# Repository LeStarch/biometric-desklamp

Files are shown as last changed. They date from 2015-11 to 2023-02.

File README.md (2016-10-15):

# Fingerprint Controlled Biometric Desk Lamp
All the files required to build the finger-print enabled LED super lamp.

Files include Arduino code, KiCad files, etc.

## Functional Diagram

Lamp Functional Design Lamp functional design

## 5V1A Power Supply
Used to power the Arduino and the cooling fan, this power supply is slightly under powered due to the narrow trace width between the components. Thus it is capible of supplying ~600mA. This is appears to be sufficient for the Teensy 3.2, finger-print scanner, and LED cooling fan.

**Needed improvments:** Trace widths need to be increased to reliably supply the advertised 1A power. 100k resistor should be replaced with surface mount equivalent.

## LED Driver
LEDs must be driven at a constant current (not voltage) in order to maximize their life expectancy. This driver produces a 1A constant ~30V supply for a high-powered LED module.  It is based on the Texas Instruments LM-3409 chip.  See: https://github.com/LeStarch/lm3409-calc for how the components were calculated.

**Needed Improvments:** 

Awaiting assembly.

**Issues Corrected in v2:** Trace widths may be too small to reliably cary 1A for LED driving. In practice, the lamp is stable, but trace widths should be increased in "an abundance of caution".

P-type MOSFET has a reversed layout and thus should be corrected in version 2.

## Nano Code (and now Teensy as well)
Code written using the Arduino libraries, which interfaces with the fingerprint reader and controls PWM signals used to drive the cooling fan and LED driver enable line.

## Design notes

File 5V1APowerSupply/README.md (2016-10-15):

5V Driver
=========

This is now unused, as it was merged into a singleton board.

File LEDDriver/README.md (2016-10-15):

Kicad Files
===========

This directory contains the necessary schematic files, net, and pcb files for the Kicad design of the biometric desklamp.

Note: the 5v driver has been added as a sub-schematic

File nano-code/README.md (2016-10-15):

Arduino Software
================

This is the software written for arduino to interface with the biometric desklamp.  This software is written in C++ and uses the arduino libraries in order to to handle IO and UART.

''Note:'' this software was developed with the help of Platform-IO and thus it is recommended that the user use Platform-IO to build/upload.

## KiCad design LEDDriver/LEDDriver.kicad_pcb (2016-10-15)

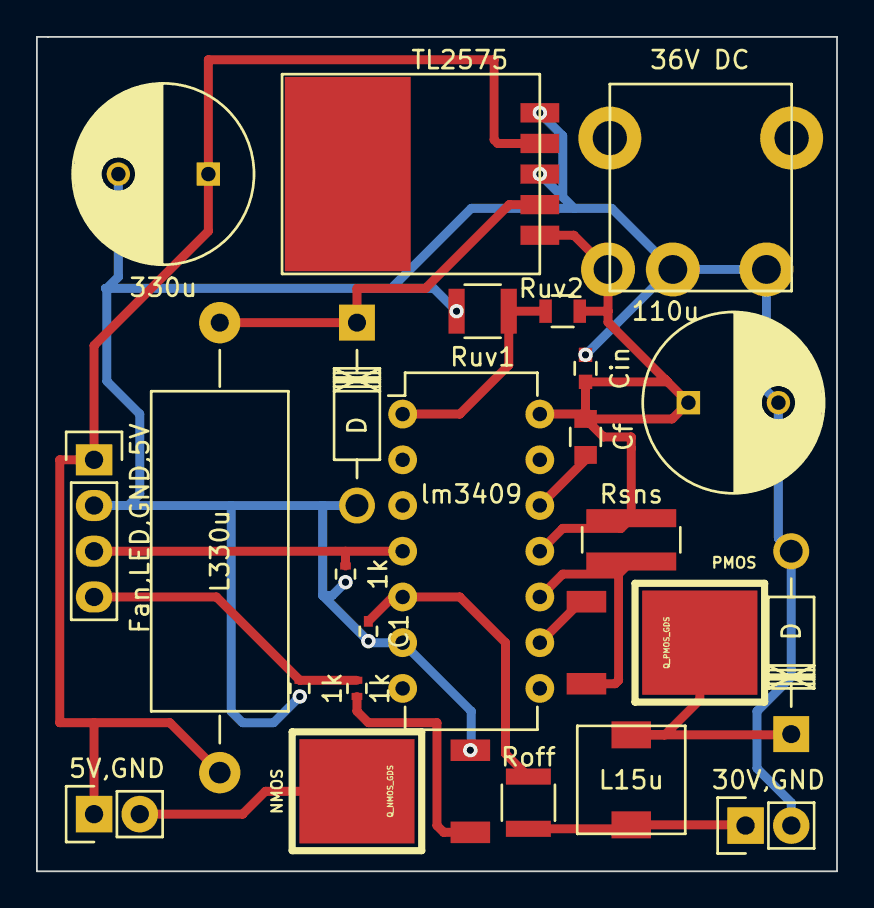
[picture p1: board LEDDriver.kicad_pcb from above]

Board: 2 copper layers, 44.5 x 46.4 mm, 24 parts (0 on the bottom side), 15 nets.

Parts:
1k, 1k#2, 1k#3: R; R_0402
5V,GND: FanOut; Pin_Header_Straight_1x02
30V,GND: ToLED; Pin_Header_Straight_1x02
36V DC: 36V DC Power; PJ-051A
110u: CP; C_Radial_D10_L16_P5
330u: 330u; C_Radial_D10_L16_P5
C1: Coff; C_0402
Cf: Cf; C_0805
Cin: Cin; C_0603
D: D_Schottky; Diode_DO-41_SOD81_Horizontal_RM10
D#2: D_Schottky; Diode_DO-41_SOD81_Horizontal_RM10
Fan,LED,GND,5V: TeensyConnector; Pin_Header_Straight_1x04
L15u: INDUCTOR; SLF6045
L330u: 330u; Resistor_Horizontal_RM25mm
NMOS: Q_NMOS_GDS; TO-252-3
PMOS: Q_PMOS_GDS; TO-252-3
Roff: Roff; R_1210
Rsns: Rsns; R_1020
Ruv1: Ruv1; R_1210
Ruv2: Ruv2; R_0805
TL2575: TL25527; TO-263
lm3409: lm3409; DIP-14_W7.62mm

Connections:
/Regulator1/5VOut: 5V,GND.1, 330u.1, Fan,LED,GND,5V.1, L330u.2, TL2575.4
GND: 1k.2, 1k#3.2, 30V,GND.2, 36V DC.2, 36V DC.3, 110u.2, 330u.2, C1.2, Cin.2, D.2, D#2.2, Fan,LED,GND,5V.2, NMOS.3, Ruv1.2, TL2575.3, TL2575.5, lm3409.6
unnamed: C1.1, Roff.2, lm3409.5
unnamed: Cf.2, lm3409.12
unnamed: D.1, L15u.1, PMOS.2
unnamed: D#2.1, L330u.1, TL2575.2
unnamed: 30V,GND.1, L15u.2, Roff.1
unnamed: Ruv1.1, Ruv2.2, lm3409.1
unnamed: 1k#3.1, Fan,LED,GND,5V.3, lm3409.4
unnamed: PMOS.1, lm3409.9
unnamed: PMOS.3, Rsns.1, lm3409.10
unnamed: 5V,GND.2, NMOS.2
unnamed: 1k.1, 1k#2.1, Fan,LED,GND,5V.4
unnamed: 1k#2.2, NMOS.1
VCC: 36V DC.1, 110u.1, Cf.1, Cin.1, Rsns.2, Ruv2.1, TL2575.1, lm3409.11, lm3409.14

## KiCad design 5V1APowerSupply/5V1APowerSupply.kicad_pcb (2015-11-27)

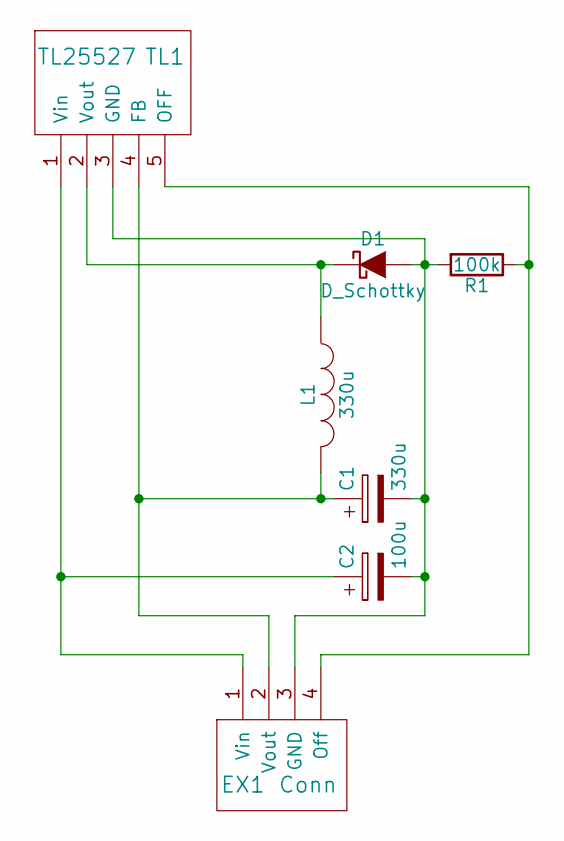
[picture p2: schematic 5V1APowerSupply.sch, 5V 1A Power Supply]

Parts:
C1: 330u; C_Radial_D10_L16_P5
C2: 100u; C_Radial_D10_L16_P5
D1: D_Schottky; Diode_DO-41_SOD81_Horizontal_RM10
EX1: Conn; Pin_Header_Straight_1x04
L1: 330u; Resistor_Horizontal_RM25mm
R1: 100k; Resistor_Horizontal_RM10mm
TL1: TL25527; TO-263

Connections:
unnamed: C1.1, EX1.2 (Vout), L1.2, TL1.4 (FB)
unnamed: C1.2, C2.2, D1.2 (A), EX1.3 (GND), R1.2, TL1.3 (GND)
unnamed: C2.1, EX1.1 (Vin), TL1.1 (Vin)
unnamed: D1.1 (K), L1.1, TL1.2 (Vout)
unnamed: EX1.4 (Off), R1.1, TL1.5 (OFF)

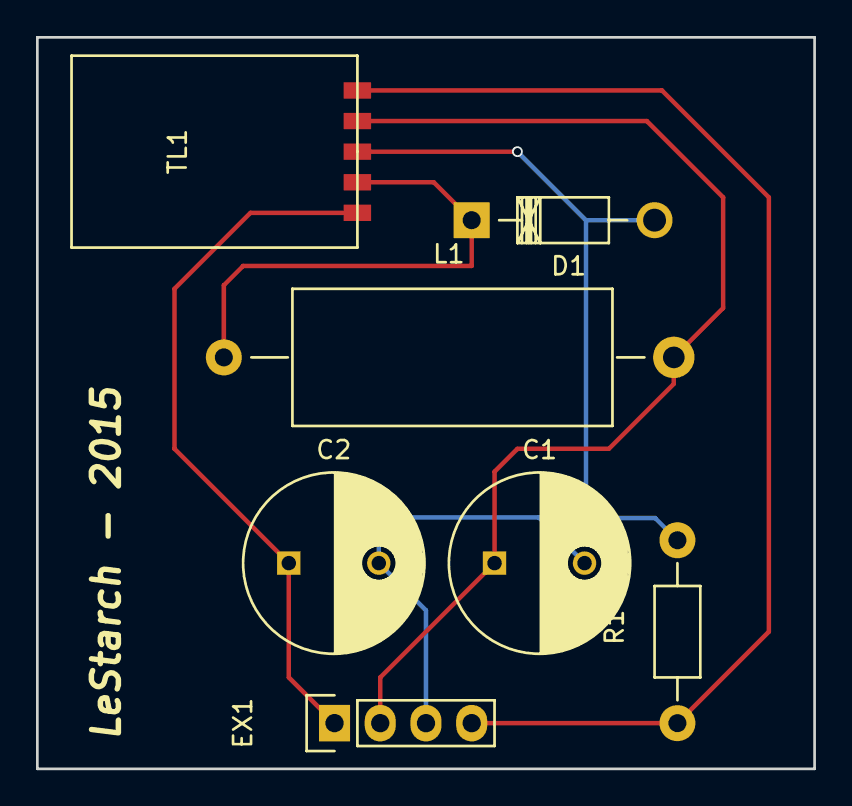
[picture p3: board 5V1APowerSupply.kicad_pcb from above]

Board: 2 copper layers, 43.2 x 40.6 mm, 7 parts (0 on the bottom side), 5 nets.

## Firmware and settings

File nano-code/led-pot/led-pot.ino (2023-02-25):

#include "config.h"


#define WINDOW_SIZE 100
#define EDGE_CUT 100
#define MAX_INPUT 1024
#define MAX_OUTPUT 255
#define OUT_33 85

void setup() {
    //Serial.begin(115200);
    //delay(500);
    pinMode(LED_PIN, OUTPUT);
    pinMode(FAN_PIN, OUTPUT);
}

unsigned long int reading() {
    static bool s_filled = false;
    static unsigned long int s_index = 0;
    static unsigned long int s_window[WINDOW_SIZE];

    s_window[s_index] = analogRead(A0);
    s_index = (s_index + 1) % WINDOW_SIZE;
    s_filled = (s_index == 0);
    // Calculate average window
    unsigned long int average = 0;
    for (unsigned long int i = 0; i < (s_filled ? WINDOW_SIZE : s_index); i++) {
        average += s_window[i];
    }
    average = average / ((s_filled) ? WINDOW_SIZE : s_index);
    return average;
}

void loop() {
    unsigned long int val = reading();
    // Map the two edge values to off or max 
    if (val < EDGE_CUT) {
        val = 0;
    } else if (val > (MAX_INPUT - EDGE_CUT)) {
        val = MAX_OUTPUT;
    }
    // Otherwise run from 33% - 66%
    else {
        val = (val * OUT_33) / MAX_INPUT + OUT_33;
    }
    //Serial.print("Value:");
    //Serial.print(val);
    //Serial.print("\n");
    // Write output   
    analogWrite(LED_PIN, val);
    analogWrite(FAN_PIN, val);
}

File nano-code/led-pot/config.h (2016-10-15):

/*
 * config.h
 *
 *  Created on: Oct 14, 2016
 *      Author: lestarch
 */
#ifndef CONFIG_H_
#define CONFIG_H_
	//Pin used to drive the LED module
    #define LED_PIN 23
    //Pin used to drive the cooling fan
    #define FAN_PIN 22
    //Time in milliseconds to allow for enrollment
    #define ENROLL_PERIOD_TIME 1000
	//Time to delay after light is toggled
    #define TOGGLE_DELAY 500
    //Time to delay on startup
	#define START_UP_DELAY 500

	//Print debug statements to USB serial
	//#define DEBUG
#endif /* CONFIG_H_ */

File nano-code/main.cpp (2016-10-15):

/*
 * main.c
 *
 *  Created on: Oct 9, 2016
 *      Author: starchmd
 */
#include <Arduino.h>

#include "scanner.h"
#include "led.h"
#include "config.h"

//Global scanner pointer
Scanner* scanner;
//Global led pointer
Led* led;
/**
 * Check if we need to enroll and then do so
 * \return 0 on success, anything else on error
 */
int check_and_enroll()
{
    int status = 0;
    uint32_t count;
    uint32_t time;
    Command roll(Command::GET_ENROLL_COUNT);
    Command finger(Command::IS_PRESS_FINGER);
    Command ret(Command::NIL);
    #ifdef DEBUG
        Serial.println("-- Checking Enrollment --");
    #endif
    //Check if there are enrolled fingers
    if ((status = scanner->send(roll,ret)) != 0)
    {
        return status;
    }
    count = ret.getPatameter();
	//Enroll count != 1 ot
    if ((status = scanner->flash(ENROLL_FLASH_COUNT, 0, 1)) != 0)
    {
        return status;
    }
    scanner->led(Scanner::ON);
    time = millis()+ENROLL_PERIOD_TIME;
    while (millis() < time)
    {
    	if ((status = scanner->send(finger,ret)) != 0)
    	{
    		return status;
    	}
    	if (count == 0 || ret.getPatameter() == 0)
    	{
			#ifdef DEBUG
				Serial.print("Need to enroll: ");
				Serial.print(count);
				Serial.print(" ");
				Serial.println(ret.getPatameter());
			#endif
			if ((status = scanner->enroll(Command::ENROLL_START, count)) != 0)
			{
				return status;
			}
			break;
    	}
    }
    status = scanner->flash(ENROLL_FLASH_COUNT, 0, 1);
    return status;
}
/**
 * Handle an error by flashing the status on the led
 * \param int status - status to flash
 */
void error(int status)
{
	#ifdef DEBUG
		Serial.print("Error detected: ");
		Serial.println(status);
	#endif
	scanner->flash(status, 1000, 10);
}
/**
 * Setup to run the loop
 */
void setup()
{
    Command open(Command::OPEN);
    Command ret(Command::NIL);
    int status = 0;
	#ifdef DEBUG
    	Serial.begin(9600);
    	delay(1000);
    	Serial.println("Starting serial debugger");
    #endif
	scanner = new Scanner(Serial1);
	scanner->flush();
	scanner->send(open,ret);
	scanner->led(Scanner::OFF);
	delay(START_UP_DELAY);
    scanner->recv(ret);
	led = new Led(LED_PIN,FAN_PIN);
    if ((status = check_and_enroll()) != 0)
    {
        error(status);
    }
}
/**
 * Loop forever
 */
void loop()
{
	int status = 0;
	bool known = false;
    if((status = scanner->indentify(known)) != 0)
    {
    	error(status);
    }
    else if (known)
    {
    	led->toggle();
    	scanner->led(Scanner::OFF);
    	delay(TOGGLE_DELAY);
    	scanner->led(Scanner::ON);
    }
}

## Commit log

2014-12-03 Fully functioning prototype. NO ERROR HANDLING
    [fingerprint.ino]
2015-11-27 lestarch: assembling LED driver, 5V 1A power supply, and fingerprint code.
    [5V1APowerSupply.kicad_pcb, 5V1APowerSupply.sch, LEDDriver.kicad_pcb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]
2016-01-16 lestarch: working prototype code
2016-01-30 lestarch: computer failure, rats abandon ship
    [fingerprint.ino]
2016-09-06 lestarch: adding design files for combined design v2.0
    [5V1APowerSupply.sch, LEDDriver.kicad_pcb, LEDDriver.sch]
2016-10-15 lestarch: fixing fan/led output
    [led.cpp]
2016-10-15 lestarch: changing resistors to pulldown resistors; adding pulldown to LED
    [LEDDriver.kicad_pcb, LEDDriver.sch]
2023-02-25 adding led potentionmeter code
